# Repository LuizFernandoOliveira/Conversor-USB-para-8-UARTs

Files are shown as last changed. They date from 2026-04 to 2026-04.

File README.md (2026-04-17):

# Conversor USB para 8 UARTs




## Descrição
Este circuito eletrônico permite realizar a comunicação serial simutânea de até 8 portas UART com um computador via USB. Esta PCB é ideal para aplicações de testes de comunicação simultânea de múltiplos sensores com um único PC.

<p align="center">
  usb2OitoUarts
</p>

---

## Descrições técnicas

- Interface USB: Dispositivo USB High-Speed de 480Mbps;
- Possui oito UARTs (UART0 até UART7) e até 11 pinos de GPIOs controlados via USB;
- Taxa de Transmissão (Baud Rate): Variável de 1200bps até 6Mbps;
- Alimentação Principal: Requer apenas 3.3V;
- Controle de Fluxo: Suporte completo a Hardware Flow Control (CTS e RTS);
- Buffering (FIFO):
  - RX FIFO: 2048 bytes por UART.
  - TX FIFO: 1024 bytes por UART.
- Configurações UART:
  - Bits de Dados: 8 bits;
  - Paridade: Ímpar, Par e Nenhuma;
  - Bits de Parada: 1 ou 2.

---

## Estrutura do repositório
Os arquivos de hardware foram desenvolvidos utilizando o KiCad 9.0.
- **`.kicad_pcb`**: Layout da placa de circuito impresso (Board).
- **`.kicad_sch`**: Esquemático eletrônico do sistema (Schematic).
- **`.kicad_pro`**: Gerenciador de projeto do KiCad (Project).

---

## Autor
**Dr. Luiz Fernando Pinto de Oliveira**

*Engenheiro Eletrônico especializado em Sistemas Embarcados e Ultra-Low Power.*
- **Website:** [FAPLO](https://faplo.webnode.page/)
- **LinkedIn:** [lfpo](https://www.linkedin.com/in/lfpo/)

---

Shield: [][cc-by-nc-nd]

This work is licensed under a
[Creative Commons Attribution-NonCommercial-NoDerivs 4.0 International License][cc-by-nc-nd].

[][cc-by-nc-nd]

[cc-by-nc-nd]: http://creativecommons.org/licenses/by-nc-nd/4.0/
[cc-by-nc-nd-image]: https://licensebuttons.net/l/by-nc-nd/4.0/88x31.png
[cc-by-nc-nd-shield]: https://img.shields.io/badge/License-CC%20BY--NC--ND%204.0-lightgrey.svg

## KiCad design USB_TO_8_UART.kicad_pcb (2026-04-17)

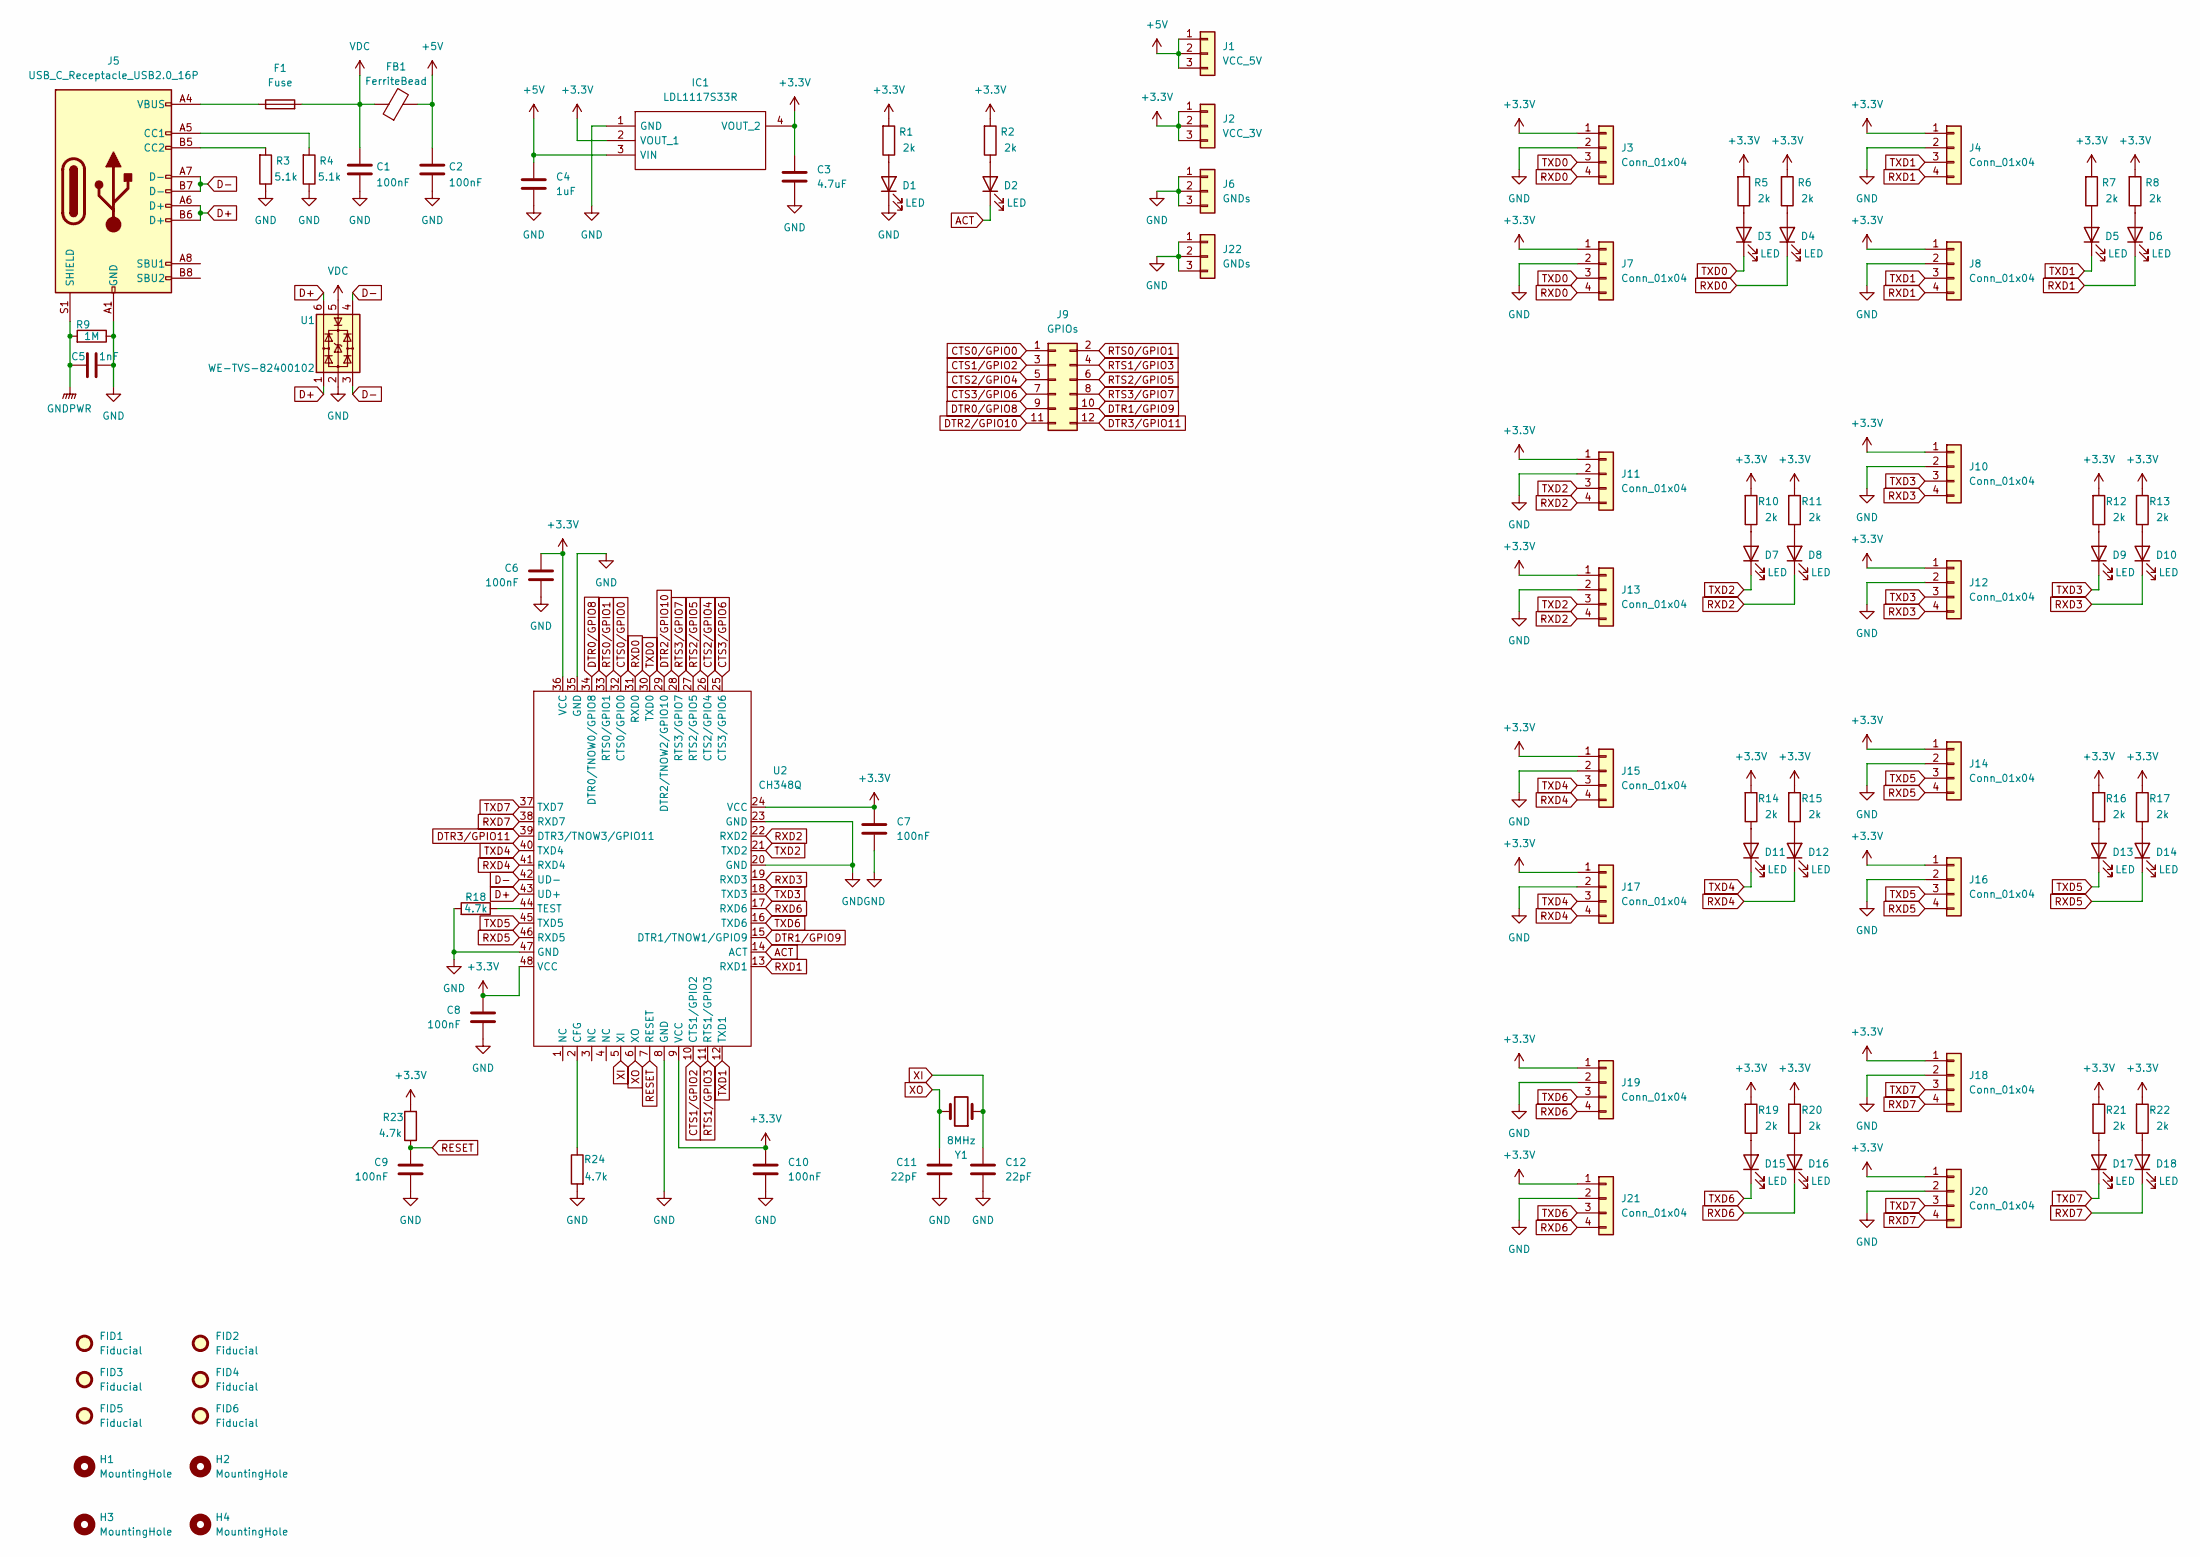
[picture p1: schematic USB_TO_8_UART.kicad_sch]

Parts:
C1, C2, C6, C7, C8, C9, C10: 100nF; C_0805_2012Metric
C3: 4.7uF; C_0805_2012Metric
C4: 1uF; C_0805_2012Metric
C5: 1nF; C_0805_2012Metric
C11, C12: 22pF; C_0805_2012Metric
D1, D2, D3, D4, D5, D6, D7, D8, D9, D10, D11, D12, D13, D14, D15, D16, D17, D18: LED; LED_0805_2012Metric
F1: Fuse; Fuse_0805_2012Metric
FB1: FerriteBead; L_0805_2012Metric
FID1, FID2, FID3, FID4, FID5, FID6: Fiducial; Fiducial_1mm_Mask2mm
H1, H2, H3, H4: MountingHole; MountingHole_3.2mm_M3_DIN965
IC1: LDL1117S33R; SOT230P700X180-4N; Manufacturer_Part_Number LDL1117S33R; Mouser Part Number 511-LDL1117S33R
J1: VCC_5V; PinHeader_1x03_P2.54mm_Vertical
J2: VCC_3V; PinHeader_1x03_P2.54mm_Vertical
J3, J4, J10, J11, J14, J15, J18, J19: Conn_01x04; PinHeader_1x04_P2.54mm_Vertical
J5: USB_C_Receptacle_USB2.0_16P; USB_C_Receptacle_HRO_TYPE-C-31-M-12
J6, J22: GNDs; PinHeader_1x03_P2.54mm_Vertical
J7, J8, J12, J13, J16, J17, J20, J21: Conn_01x04; JST_XH_S4B-XH-A_1x04_P2.50mm_Horizontal
J9: GPIOs; PinHeader_2x06_P2.54mm_Vertical
R1, R2, R5, R6, R7, R8, R10, R11, R12, R13, R14, R15, R16, R17, R19, R20, R21, R22: 2k; R_0805_2012Metric
R3, R4: 5.1k; R_0805_2012Metric
R9: 1M; R_0805_2012Metric
R18, R23, R24: 4.7k; R_0805_2012Metric
U1: WE-TVS-82400102; SOT-23-6
U2: CH348Q
Y1: 8MHz; Crystal_SMD_3225-4Pin_3.2x2.5mm

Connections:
+3.3V: C3.1, C6.1, C7.1, C8.1, C10.1, IC1.2 (VOUT_1), IC1.4 (VOUT_2), J2.1, J2.2, J2.3, J3.1, J4.1, J7.1, J8.1, J10.1, J11.1, J12.1, J13.1, J14.1, J15.1, J16.1, J17.1, J18.1, J19.1, J20.1, J21.1, R1.2, R2.2, R5.2, R6.2, R7.2, R8.2, R10.2, R11.2, R12.2, R13.2, R14.2, R15.2, R16.2, R17.2, R19.2, R20.2, R21.2, R22.2, R23.2, U2.9 (VCC), U2.24 (VCC), U2.36 (VCC), U2.48 (VCC)
+5V: C2.1, C4.1, FB1.2, IC1.3 (VIN), J1.1, J1.2, J1.3
ACT: D2.1 (K), U2.14 (ACT)
CTS0/GPIO0: J9.1, U2.32 (CTS0/GPIO0)
CTS1/GPIO2: J9.3, U2.10 (CTS1/GPIO2)
CTS2/GPIO4: J9.5, U2.26 (CTS2/GPIO4)
CTS3/GPIO6: J9.7, U2.25 (CTS3/GPIO6)
D+: J5.A6 (D+), J5.B6 (D+), U1.1, U1.6, U2.43 (UD+)
D-: J5.A7 (D-), J5.B7 (D-), U1.3, U1.4, U2.42 (UD-)
DTR0/GPIO8: J9.9, U2.34 (DTR0/TNOW0/GPIO8)
DTR1/GPIO9: J9.10, U2.15 (DTR1/TNOW1/GPIO9)
DTR2/GPIO10: J9.11, U2.29 (DTR2/TNOW2/GPIO10)
DTR3/GPIO11: J9.12, U2.39 (DTR3/TNOW3/GPIO11)
GND: C1.2, C2.2, C3.2, C4.2, C5.2, C6.2, C7.2, C8.2, C9.2, C10.2, C11.2, C12.2, D1.1 (K), IC1.1 (GND), J3.2, J4.2, J5.A1 (GND), J5.A12 (GND), J5.B1 (GND), J5.B12 (GND), J6.1, J6.2, J6.3, J7.2, J8.2, J10.2, J11.2, J12.2, J13.2, J14.2, J15.2, J16.2, J17.2, J18.2, J19.2, J20.2, J21.2, J22.1, J22.2, J22.3, R3.1, R4.1, R9.1, R18.2, R24.2, U1.2, U2.8 (GND), U2.20 (GND), U2.23 (GND), U2.35 (GND), U2.47 (GND)
GNDPWR: C5.1, J5.S1 (SHIELD), R9.2
unnamed: D1.2 (A), R1.1
unnamed: D2.2 (A), R2.1
unnamed: D3.2 (A), R5.1
unnamed: D4.2 (A), R6.1
unnamed: D5.2 (A), R7.1
unnamed: D6.2 (A), R8.1
unnamed: D7.2 (A), R10.1
unnamed: D8.2 (A), R11.1
unnamed: D9.2 (A), R12.1
unnamed: D10.2 (A), R13.1
unnamed: D11.2 (A), R14.1
unnamed: D12.2 (A), R15.1
unnamed: D13.2 (A), R16.1
unnamed: D14.2 (A), R17.1
unnamed: D15.2 (A), R19.1
unnamed: D16.2 (A), R20.1
unnamed: D17.2 (A), R21.1
unnamed: D18.2 (A), R22.1
unnamed: F1.1, J5.A4 (VBUS), J5.A9 (VBUS), J5.B4 (VBUS), J5.B9 (VBUS)
unnamed: J5.A5 (CC1), R4.2
unnamed: J5.B5 (CC2), R3.2
unnamed: R24.1, U2.2 (CFG)
unnamed: R18.1, U2.44 (TEST)
RESET: C9.1, R23.1, U2.7 (RESET)
RTS0/GPIO1: J9.2, U2.33 (RTS0/GPIO1)
RTS1/GPIO3: J9.4, U2.11 (RTS1/GPIO3)
RTS2/GPIO5: J9.6, U2.27 (RTS2/GPIO5)
RTS3/GPIO7: J9.8, U2.28 (RTS3/GPIO7)
RXD0: D4.1 (K), J3.4, J7.4, U2.31 (RXD0)
RXD1: D6.1 (K), J4.4, J8.4, U2.13 (RXD1)
RXD2: D8.1 (K), J11.4, J13.4, U2.22 (RXD2)
RXD3: D10.1 (K), J10.4, J12.4, U2.19 (RXD3)
RXD4: D12.1 (K), J15.4, J17.4, U2.41 (RXD4)
RXD5: D14.1 (K), J14.4, J16.4, U2.46 (RXD5)
RXD6: D16.1 (K), J19.4, J21.4, U2.17 (RXD6)
RXD7: D18.1 (K), J18.4, J20.4, U2.38 (RXD7)
TXD0: D3.1 (K), J3.3, J7.3, U2.30 (TXD0)
TXD1: D5.1 (K), J4.3, J8.3, U2.12 (TXD1)
TXD2: D7.1 (K), J11.3, J13.3, U2.21 (TXD2)
TXD3: D9.1 (K), J10.3, J12.3, U2.18 (TXD3)
TXD4: D11.1 (K), J15.3, J17.3, U2.40 (TXD4)
TXD5: D13.1 (K), J14.3, J16.3, U2.45 (TXD5)
TXD6: D15.1 (K), J19.3, J21.3, U2.16 (TXD6)
TXD7: D17.1 (K), J18.3, J20.3, U2.37 (TXD7)
VDC: C1.1, F1.2, FB1.1, U1.5
XI: C12.1, U2.5 (XI), Y1.1
XO: C11.1, U2.6 (XO), Y1.2

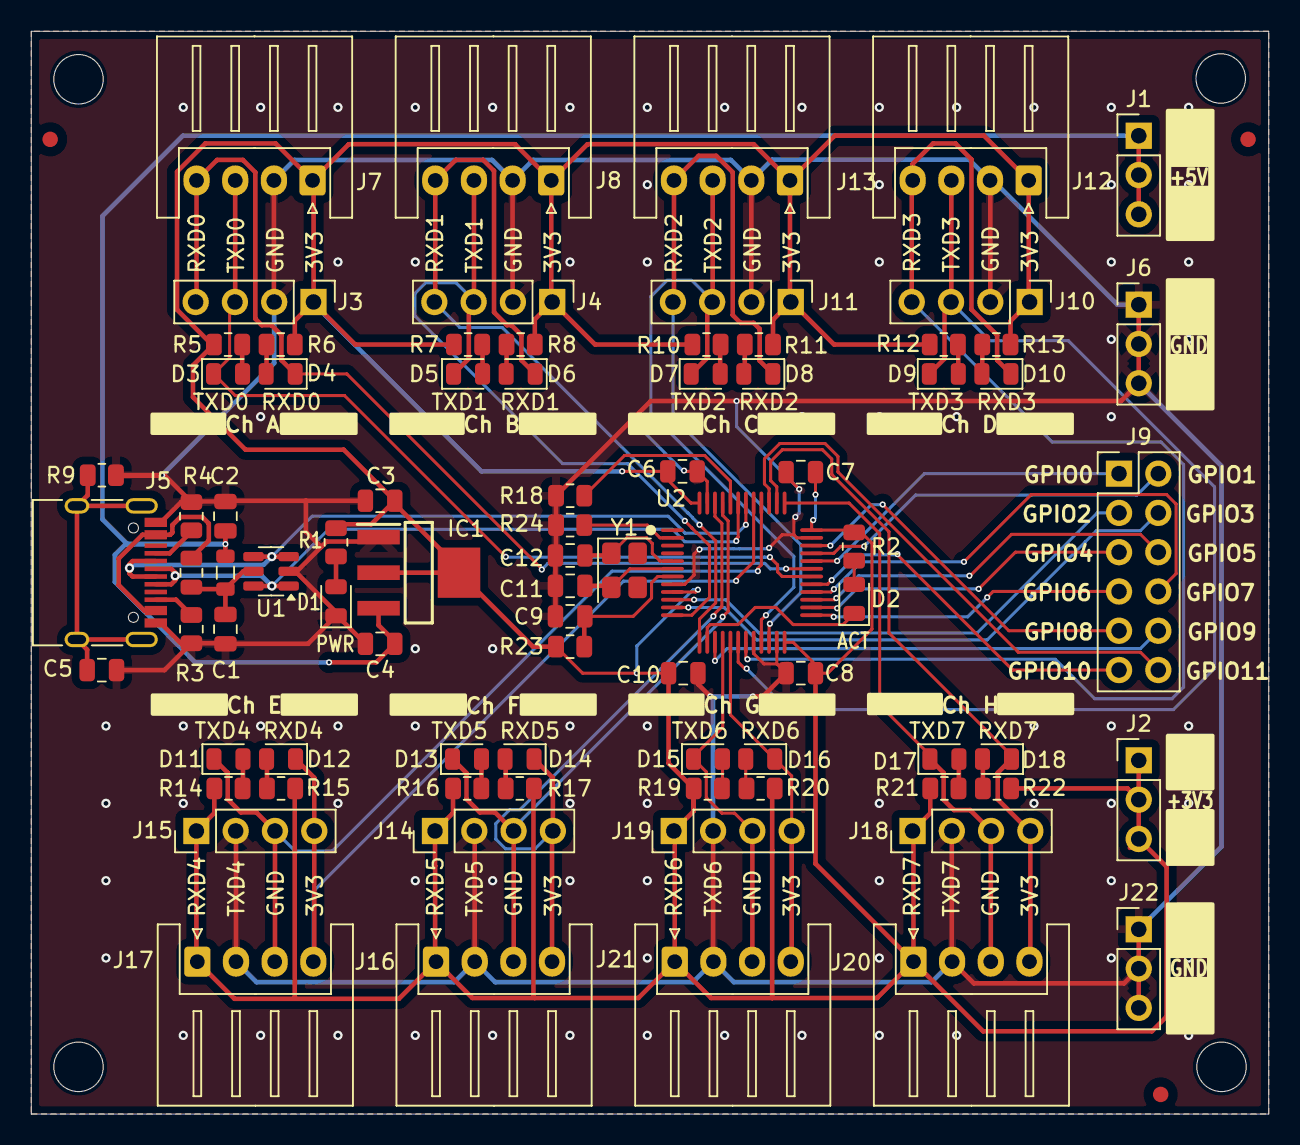
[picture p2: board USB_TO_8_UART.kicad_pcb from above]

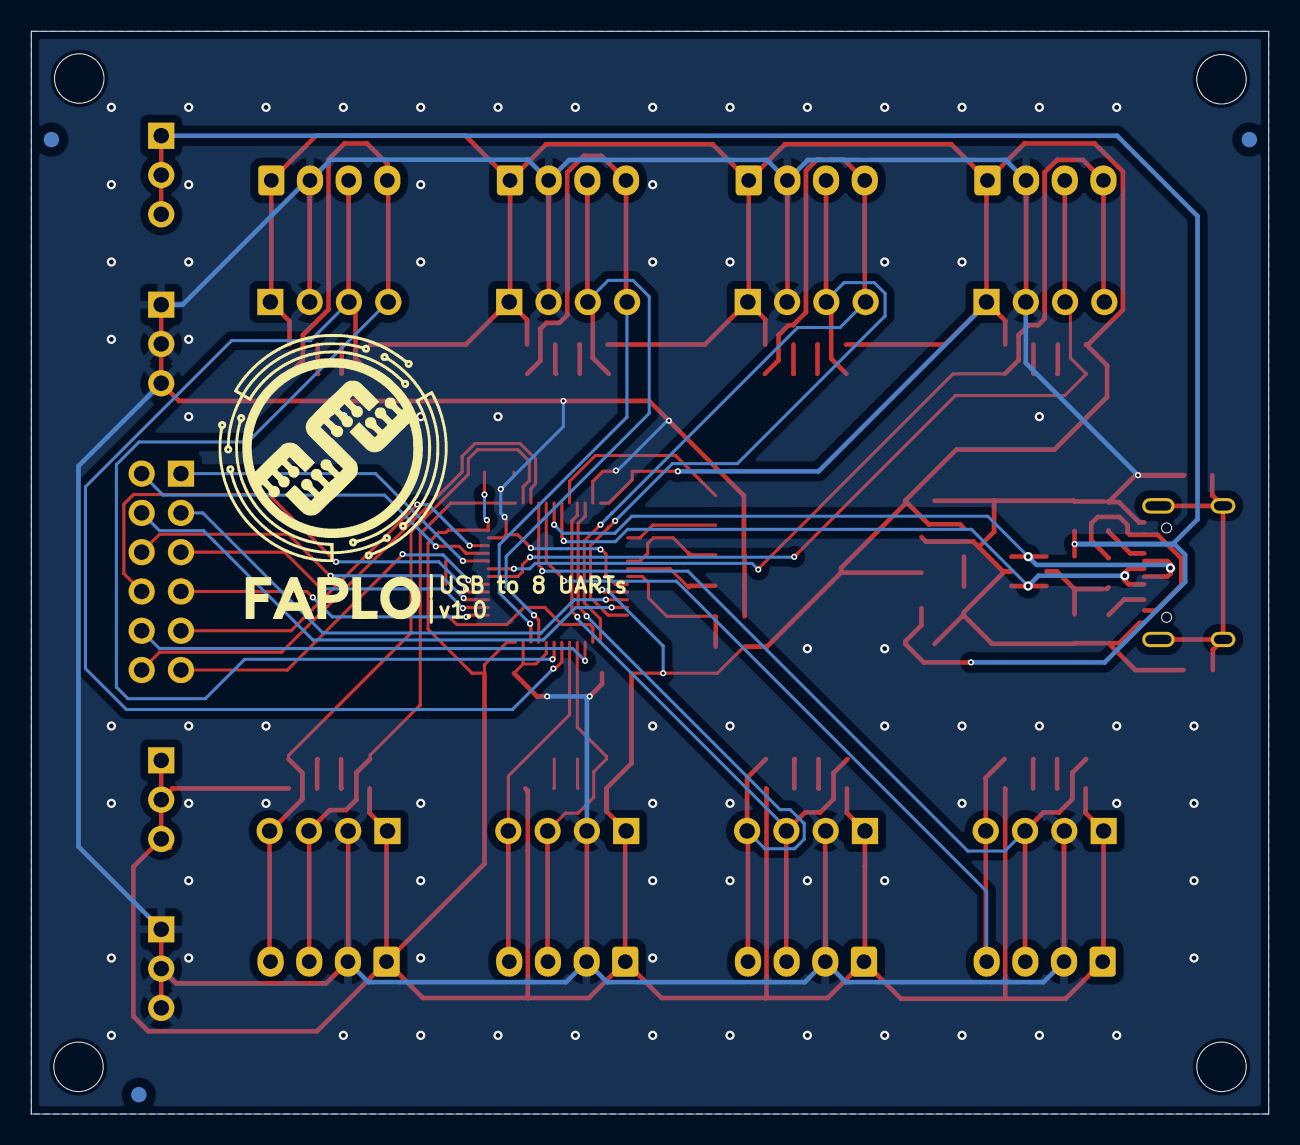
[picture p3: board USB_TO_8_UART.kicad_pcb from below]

Board: 2 copper layers, 80.0 x 70.0 mm, 92 parts (3 on the bottom side), 62 nets.

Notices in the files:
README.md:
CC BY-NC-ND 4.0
